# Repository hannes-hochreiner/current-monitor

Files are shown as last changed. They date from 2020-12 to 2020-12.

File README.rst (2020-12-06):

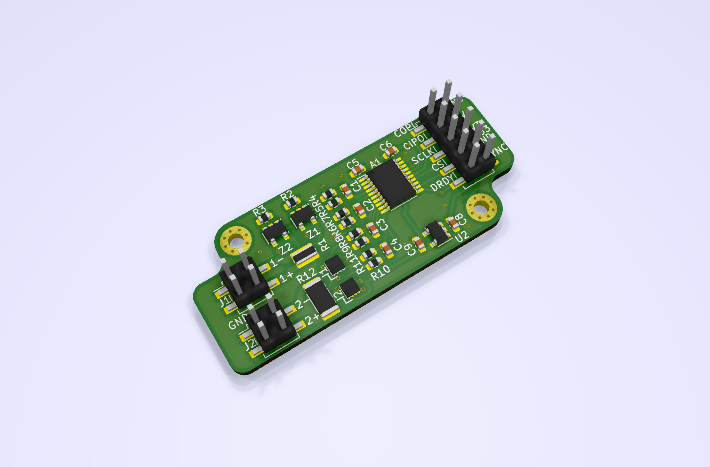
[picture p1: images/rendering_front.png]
rendering of the pcb


Current Monitor
~~~~~~~~~~~~~~~

A simple current monitor.

Requirements
============

Measure the current in the range of 150 mA to 1 µA (about 104 dB dynamic range) on a 100 µs (10 kHz) timescale.

Main Parts
==========

Current Sense Element
---------------------

ZXCT1110W5-7
............

`Datasheet <https://www.diodes.com/assets/Datasheets/ZXCT1107_10.pdf>`_

+------------------------+-------------------+
|Manufacturer            |Diodes Incorporated|
+------------------------+-------------------+
|Manufacturer Part Number|ZXCT1110W5-7       |
+------------------------+-------------------+
|Digi-Key Part Number    |ZXCT1110W5-7DICT-ND|
+------------------------+-------------------+

+------------+----------------------------+-------------------------+
|Parameter   |Equation                    |Value                    |
+============+============================+=========================+
|V_sense_max |                            | 0.3 V                   |
+------------+----------------------------+-------------------------+
|I_sense_max |                            | 0.15 A                  |
+------------+----------------------------+-------------------------+
|R_sense     | V / I                      | 2 Ohm                   |
+------------+----------------------------+-------------------------+
|I_out_max   | 4e-3 A/V * V_sense_max     | 1.2 mA                  |
+------------+----------------------------+-------------------------+
|R_gain      | ADC_full_scale / I_out_max | 1.2 V / 1.2 mA = 1 kOhm |
+------------+----------------------------+-------------------------+
|Gain        | V_out/V_sense              | 1.2 / 0.3 = 4           |
+------------+----------------------------+-------------------------+
|            | 2 V_sense / I_sense        |                         |
+------------+----------------------------+-------------------------+

INA381
......

`Datasheet <https://www.ti.com/lit/ds/symlink/ina381.pdf>`_

+--------------------------+---------------------------------+
| Manufacturer             | Texas Instruments               |
+--------------------------+---------------------------------+
| Manufacturer Part Number | INA381A1IDSGR                   |
+--------------------------+---------------------------------+
| Digi-Key Part Number     | 296-50475-1-ND                  |
+--------------------------+---------------------------------+

+------------+-----------------------------------+------------+
|Parameter   |Equation                           |Value       |
+============+===================================+============+
|I_sense_max |                                   | 0.15 A     |
+------------+-----------------------------------+------------+
|R_sense     | V_full_scale / gain / I_sense_max | 0.4 Ohm    |
+------------+-----------------------------------+------------+
|V_sense_max | I_sense_max * R_sense             | 0.06 V     |
+------------+-----------------------------------+------------+
|V_out_max   | I_sense_max * R_sense * gain      | 1.2 V      |
+------------+-----------------------------------+------------+

Others
......

https://datasheets.maximintegrated.com/en/ds/MAX9934.pdf

ADC
---

ADS131M04
.........

`Datasheet <https://www.ti.com/lit/ds/symlink/ads131m04.pdf>`_

+--------------------------+------------------------+
| Manufacturer             | Texas Instruments      |
+--------------------------+------------------------+
| Manufacturer Part Number | ADS131M04IPWR          |
+--------------------------+------------------------+
| Digi-Key Part Number     | 296-ADS131M04IPWRCT-ND	|
+--------------------------+------------------------+

+----------------------+-----------+
| Parameter            | Value     |
+======================+===========+
| full-scale           | 0-1.2 V   |
+----------------------+-----------+
| OSR                  | 256       |
+----------------------+-----------+
| CLKIN                | 8.192 MHz |
+----------------------+-----------+
| data rate            | 16 kHz    |
+----------------------+-----------+
| effective resolution | 17.8 bit  |
+----------------------+-----------+
| SPI clock            | > 2.5 MHz |
+----------------------+-----------+

min Voltage = 1.2 / Math.pow(2,24) * Math.pow(2,24-17.8) * 1e6 = 10.5 µV => 0.65 µA lower limit

Clock
-----

SIT1602BI
.........

+--------------------------+------------------------------------+
| Manufacturer             | SiTime                             |
+--------------------------+------------------------------------+
| Manufacturer Part Number | SIT1602BI-21-XXE-8.192000G         |
+--------------------------+------------------------------------+
| Digi-Key Part Number     | 1473-SIT1602BI-21-XXE-8.192000G-ND |
+--------------------------+------------------------------------+

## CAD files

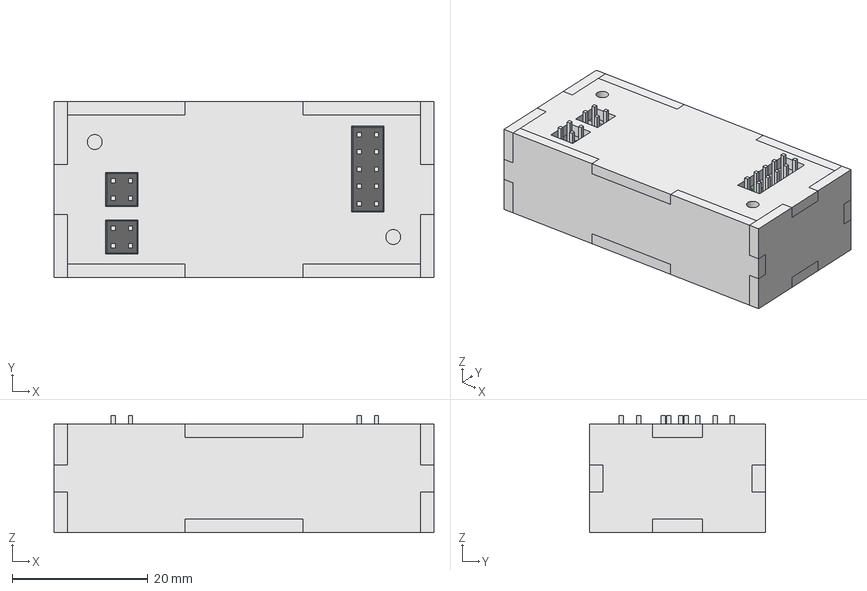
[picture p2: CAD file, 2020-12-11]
box/box.FCStd
56.0 x 26.0 x 17.3 mm
Bottom
Top
front
back
left
right
Combi1
Combi2
Combi3
Combi4
corner001
corner002
corner003
corner004
corner005
corner006
corner007
corner008

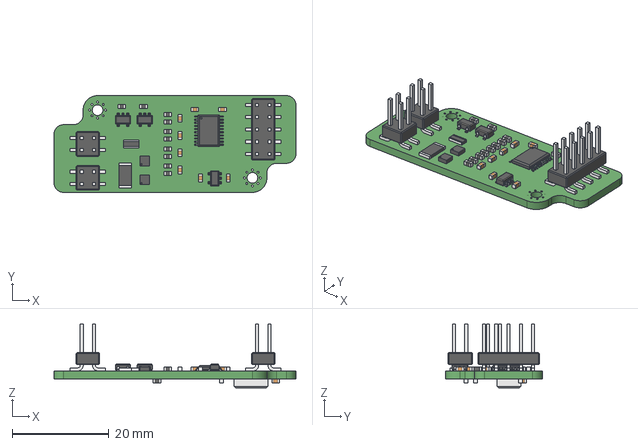
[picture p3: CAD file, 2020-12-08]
box/current-monitor.step
50.0 x 20.0 x 13.2 mm

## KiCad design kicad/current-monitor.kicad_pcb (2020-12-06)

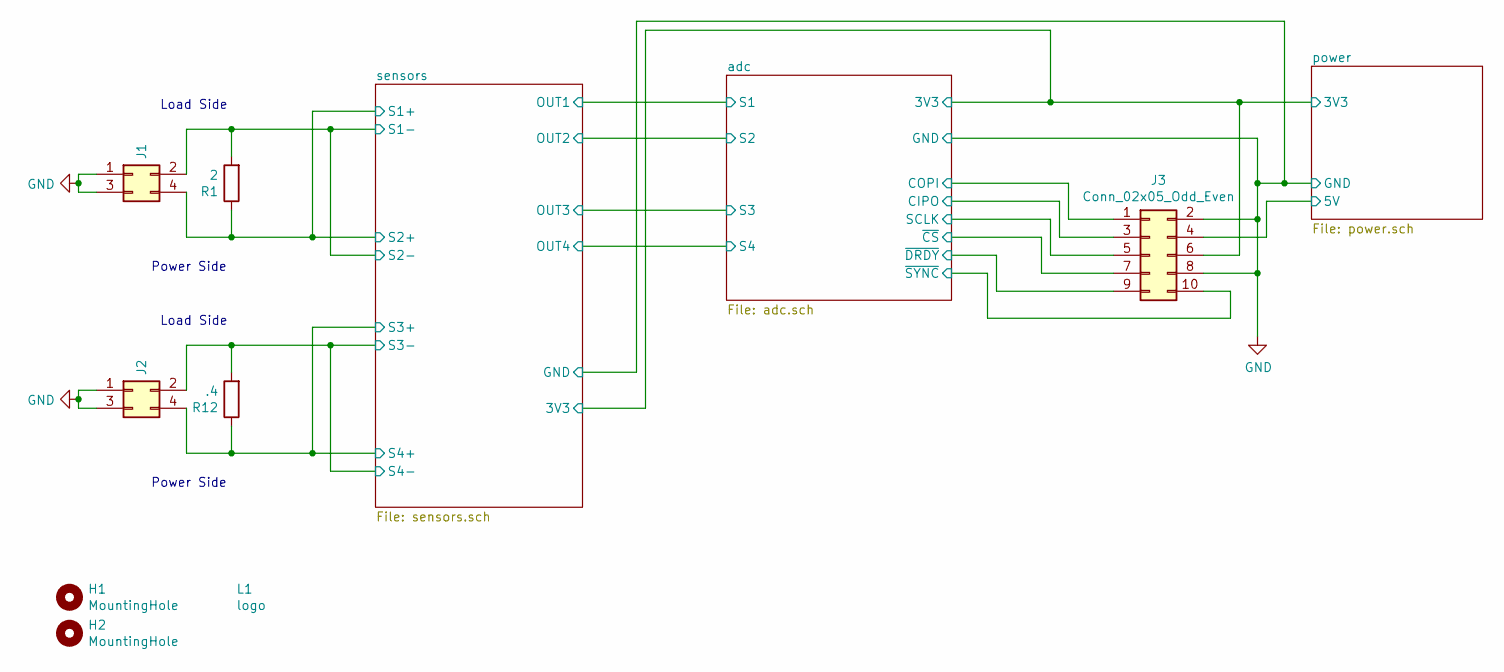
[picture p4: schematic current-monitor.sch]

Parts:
H1, H2: MountingHole; MountingHole_2.2mm_M2_Pad_Via
J1, J2: Conn_02x02_Odd_Even; PinHeader_2x02_P2.54mm_Vertical_SMD
J3: Conn_02x05_Odd_Even; PinHeader_2x05_P2.54mm_Vertical_SMD; Manufacturer Part Number 10129383-910002ALF; Digi-Key Part Number 609-10129383-910002ALFCT-ND
L1: logo
R1: 2; R_0612_1632Metric; Manufacturer Part Number LTR18EZPF2R00; Digi-Key Part Number RHM2YCT-ND
R12: .4; R_2010_5025Metric; Manufacturer Part Number WSLT2010R4000FEB18; Digi-Key Part Number WSLTA-.400CT-ND

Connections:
/adc/3V3: J3.6; also elsewhere on the board
/adc/CIPO: J3.3; also elsewhere on the board
/adc/COPI: J3.1; also elsewhere on the board
/adc/SCLK: J3.5; also elsewhere on the board
/adc/~CS: J3.7; also elsewhere on the board
/adc/~DRDY: J3.9; also elsewhere on the board
/adc/~SYNC: J3.10; also elsewhere on the board
/power/5V: J3.4; also elsewhere on the board
/sensors/S1+: J1.4, R1.1; also elsewhere on the board
/sensors/S1-: J1.2, R1.2; also elsewhere on the board
/sensors/S3+: J2.4, R12.1; also elsewhere on the board
/sensors/S3-: J2.2, R12.2; also elsewhere on the board
GND: J1.1, J1.3, J2.1, J2.3, J3.2, J3.8; also elsewhere on the board

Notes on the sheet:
Power Side
Load Side

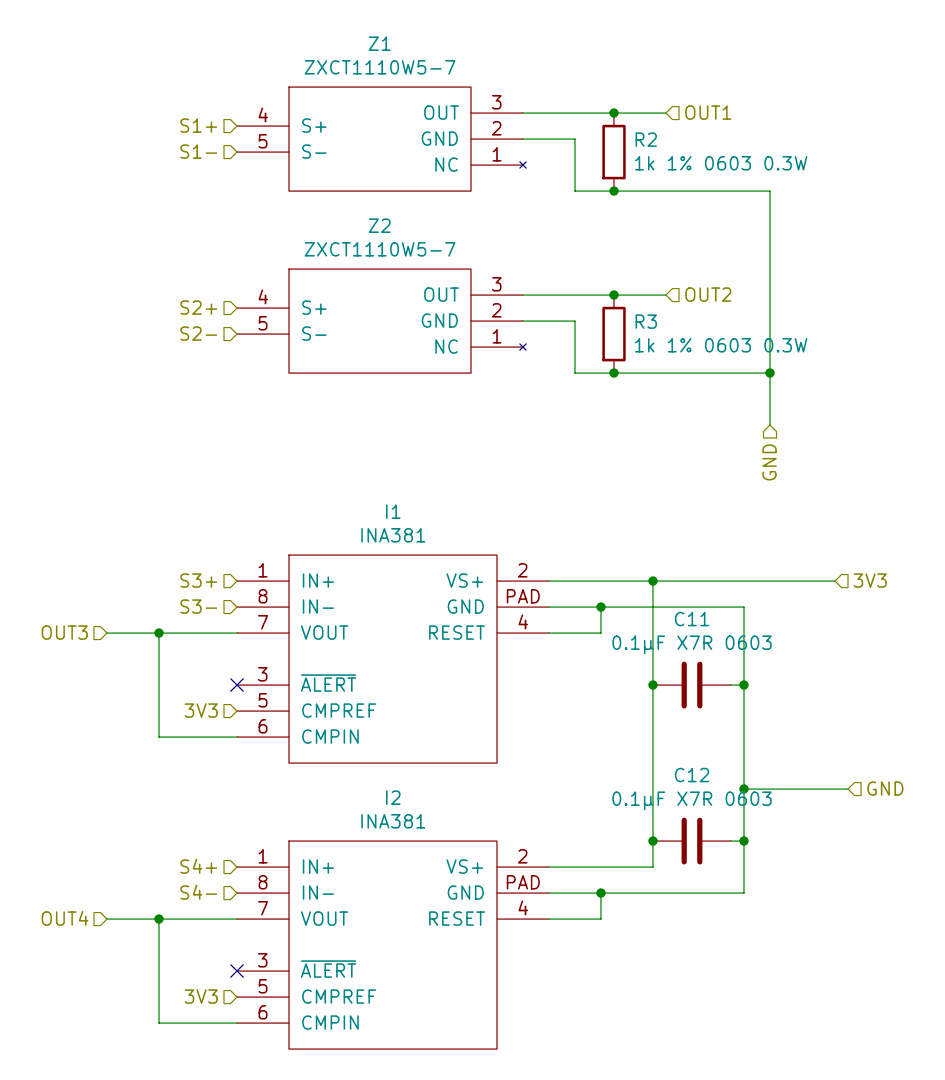
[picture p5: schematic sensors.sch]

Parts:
C11, C12: 0.1µF X7R 0603; C_0603_1608Metric
I1, I2: INA381; INA381-WSON; Manufacturer Part Number INA381A1IDSGR; Digi-Key Part Number 296-50475-1-ND
R2, R3: 1k 1% 0603 0.3W; R_0603_1608Metric
Z1, Z2: ZXCT1110W5-7; SOT-23-5; Manufacturer Part Number ZXCT1110W5-7; Digi-Key Part Number ZXCT1110W5-7DICT-ND

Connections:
/adc/3V3: C11.2, C12.2, I1.2 (VS+), I1.5 (CMPREF), I2.2 (VS+), I2.5 (CMPREF); also elsewhere on the board
/sensors/OUT1: R2.1, Z1.3 (OUT); also elsewhere on the board
/sensors/OUT2: R3.1, Z2.3 (OUT); also elsewhere on the board
/sensors/OUT3: I1.6 (CMPIN), I1.7 (VOUT); also elsewhere on the board
/sensors/OUT4: I2.6 (CMPIN), I2.7 (VOUT); also elsewhere on the board
/sensors/S1+: Z1.4 (S+), Z2.4 (S+); also elsewhere on the board
/sensors/S1-: Z1.5 (S-), Z2.5 (S-); also elsewhere on the board
/sensors/S3+: I1.1 (IN+), I2.1 (IN+); also elsewhere on the board
/sensors/S3-: I1.8 (IN-), I2.8 (IN-); also elsewhere on the board
GND: C11.1, C12.1, I1.4 (RESET), I1.PAD (GND), I2.4 (RESET), I2.PAD (GND), R2.2, R3.2, Z1.2 (GND), Z2.2 (GND); also elsewhere on the board

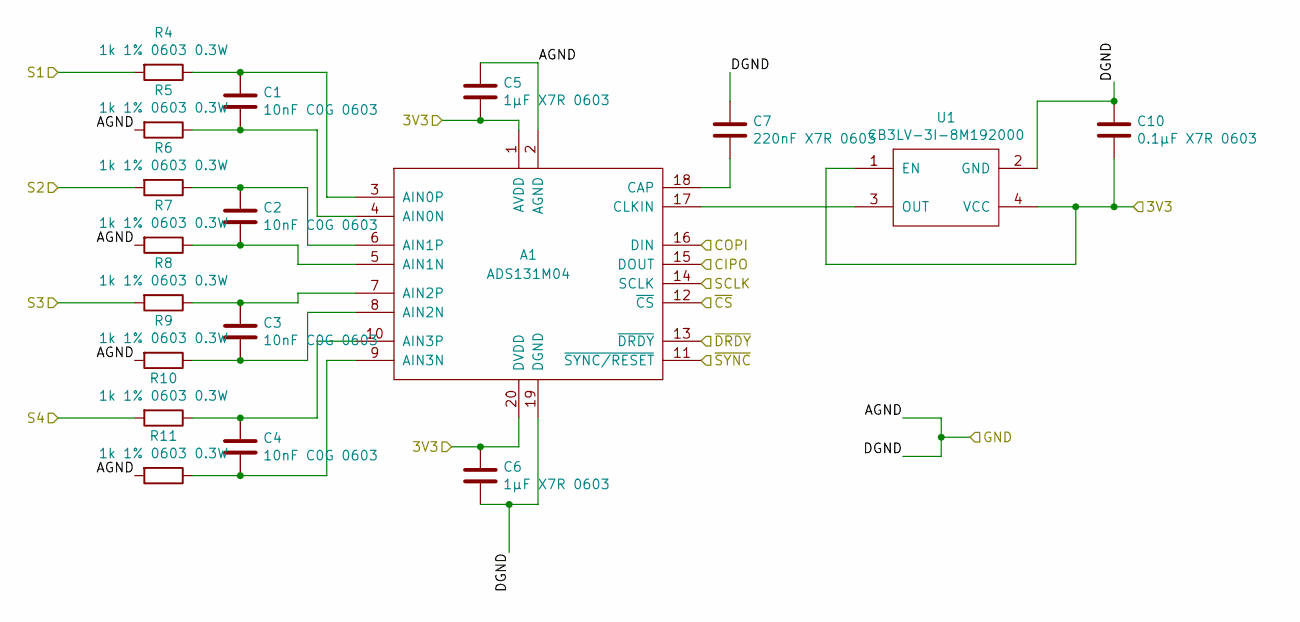
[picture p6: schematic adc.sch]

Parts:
A1: ADS131M04; TSSOP-20_4.4x6.5mm_P0.65mm; Manufacturer Part Number ADS131M04IPWR; Digi-Key Part Number 296-ADS131M04IPWRCT-ND
C1, C2, C3, C4: 10nF C0G 0603; C_0603_1608Metric
C5, C6: 1µF X7R 0603; C_0603_1608Metric
C7: 220nF X7R 0603; C_0603_1608Metric
C10: 0.1µF X7R 0603; C_0603_1608Metric
R4, R5, R6, R7, R8, R9, R10, R11: 1k 1% 0603 0.3W; R_0603_1608Metric
U1: CB3LV-3I-8M192000; Manufacturer Part Number CB3LV-3I-8M192000; Digi-Key Part Number 110-CB3LV-3I-8M192000CT-ND

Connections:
/adc/3V3: A1.1 (AVDD), A1.20 (DVDD), C5.2, C6.1, C10.2, U1.1 (EN), U1.4 (VCC); also elsewhere on the board
/adc/CIPO: A1.15 (DOUT); also elsewhere on the board
/adc/COPI: A1.16 (DIN); also elsewhere on the board
/adc/SCLK: A1.14 (SCLK); also elsewhere on the board
/adc/~CS: A1.12 (~CS); also elsewhere on the board
/adc/~DRDY: A1.13 (~DRDY); also elsewhere on the board
/adc/~SYNC: A1.11 (~SYNC/RESET); also elsewhere on the board
/sensors/OUT1: R4.2; also elsewhere on the board
/sensors/OUT2: R6.2; also elsewhere on the board
/sensors/OUT3: R8.2; also elsewhere on the board
/sensors/OUT4: R10.2; also elsewhere on the board
GND: A1.2 (AGND), A1.19 (DGND), C5.1, C6.2, C7.1, C10.1, R5.2, R7.2, R9.2, R11.2, U1.2 (GND); also elsewhere on the board
unnamed: A1.3 (AIN0P), C1.1, R4.1
unnamed: A1.4 (AIN0N), C1.2, R5.1
unnamed: A1.5 (AIN1N), C2.2, R7.1
unnamed: A1.6 (AIN1P), C2.1, R6.1
unnamed: A1.7 (AIN2P), C3.1, R8.1
unnamed: A1.8 (AIN2N), C3.2, R9.1
unnamed: A1.9 (AIN3N), C4.2, R11.1
unnamed: A1.10 (AIN3P), C4.1, R10.1
unnamed: A1.17 (CLKIN), U1.3 (OUT)
unnamed: A1.18 (CAP), C7.2

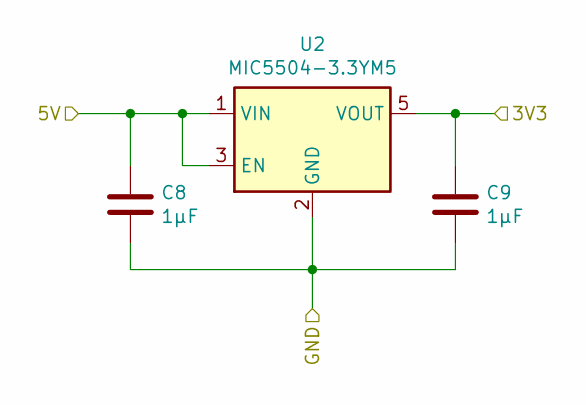
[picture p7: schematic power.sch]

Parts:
C8, C9: 1µF; C_0603_1608Metric
U2: MIC5504-3.3YM5; SOT-23-5

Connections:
/adc/3V3: C9.1, U2.5 (VOUT); also elsewhere on the board
/power/5V: C8.1, U2.1 (VIN), U2.3 (EN); also elsewhere on the board
GND: C8.2, C9.2, U2.2 (GND); also elsewhere on the board

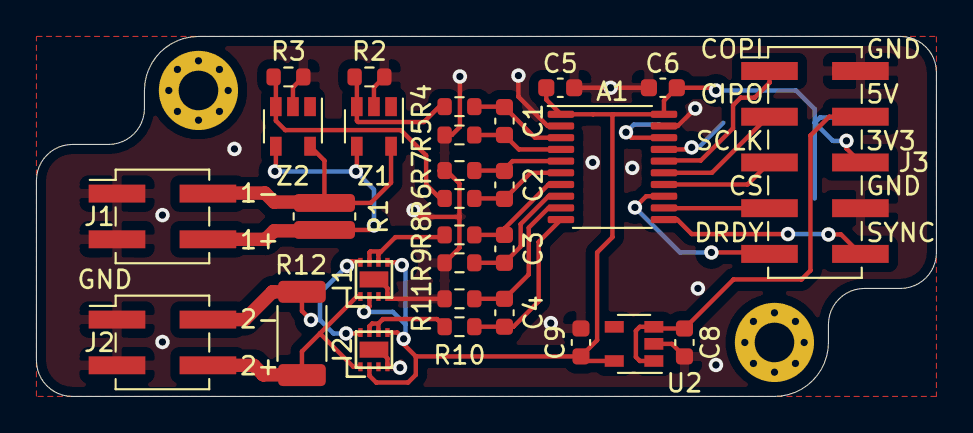
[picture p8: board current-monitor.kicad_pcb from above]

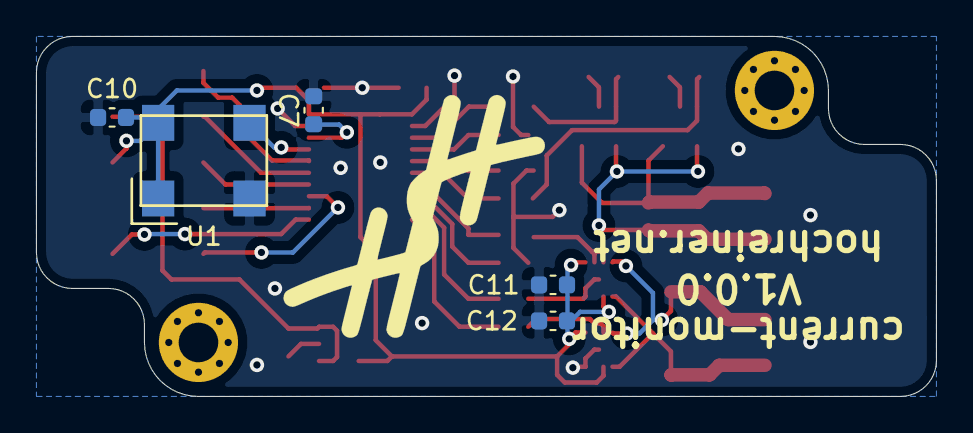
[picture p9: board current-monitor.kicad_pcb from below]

Board: 2 copper layers, 50.0 x 20.0 mm, 37 parts (6 on the bottom side), 27 nets.

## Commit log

2020-11-29 started layout
    [adc.sch, current-monitor.kicad_pcb, current-monitor.sch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]
2020-12-03 add second R_sense
    [current-monitor.kicad_pcb, current-monitor.sch]
2020-12-05 move clock to back
    [current-monitor.kicad_pcb, current-monitor.sch]
2020-12-06 put markings on pcb
    [current-monitor.kicad_pcb, current-monitor.sch]
2020-12-06 switch clock and add bypass
    [adc.sch, current-monitor.kicad_pcb, current-monitor.sch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]
2020-12-08 start box design
    [box.FCStd, current-monitor.step]
2020-12-11 finish basic design
    [box.FCStd]
